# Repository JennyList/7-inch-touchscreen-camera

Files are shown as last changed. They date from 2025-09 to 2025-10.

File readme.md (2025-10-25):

# A camera enclosure for the 1st gen Rpi 7" touch screen, with interchangeable camera modules

Jenny List 2025
CC-BY-SA 4.0

## About

I need a camera mule, on which to test experimental digital camera designs. I had an RPi 4 and a 1st-gen Pi 7" touch screen, so I've made this camera enclosure. Think of it as a very chunky 7" tablet with a mounting on the rear for a modular 3D printed camera carrier. As shipped, it comes with a module for the RPi HQ camera.

For my needs it doesn't come with a battery, it will always be used in a static situation or as part of a rig  where USB-C power is available.
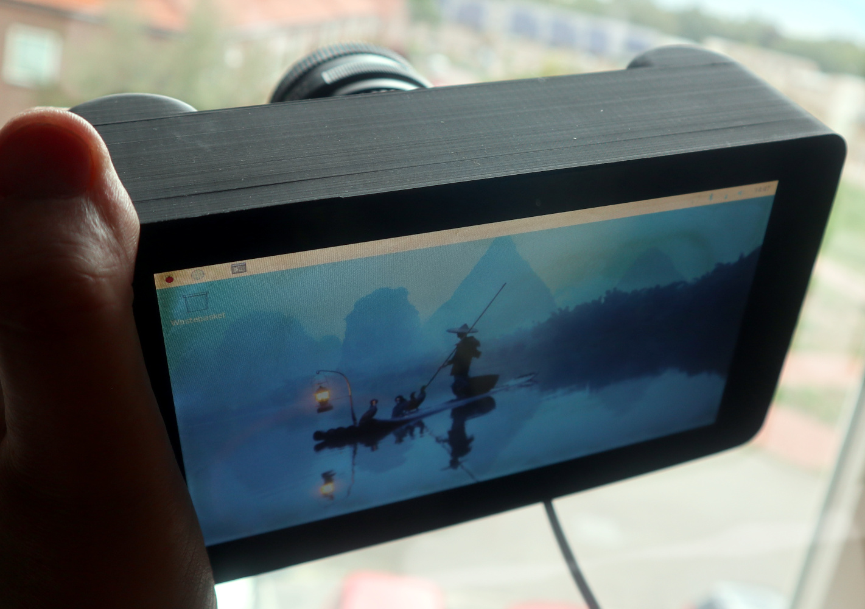
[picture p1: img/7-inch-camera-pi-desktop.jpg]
A picture of the camera.


## You Will Need:

Prints of the following modules from 7-inch-camera.scad. Use full supports and a brim.
1. cameraChassis()
2. cameraGripPanel()
3. HQCameraFrontPlate()

A print of the contents of camera-collar.scad. Use full supports and a brim.

A Pi 1/2/3/4 model B+

A 1st gen 7" Raspberry Pi touch screen and mounting kit.

4 M3 screws for the screen.

Assorted self-tapping screws for assembly.

## To Assemble:

The parts appear as follows:

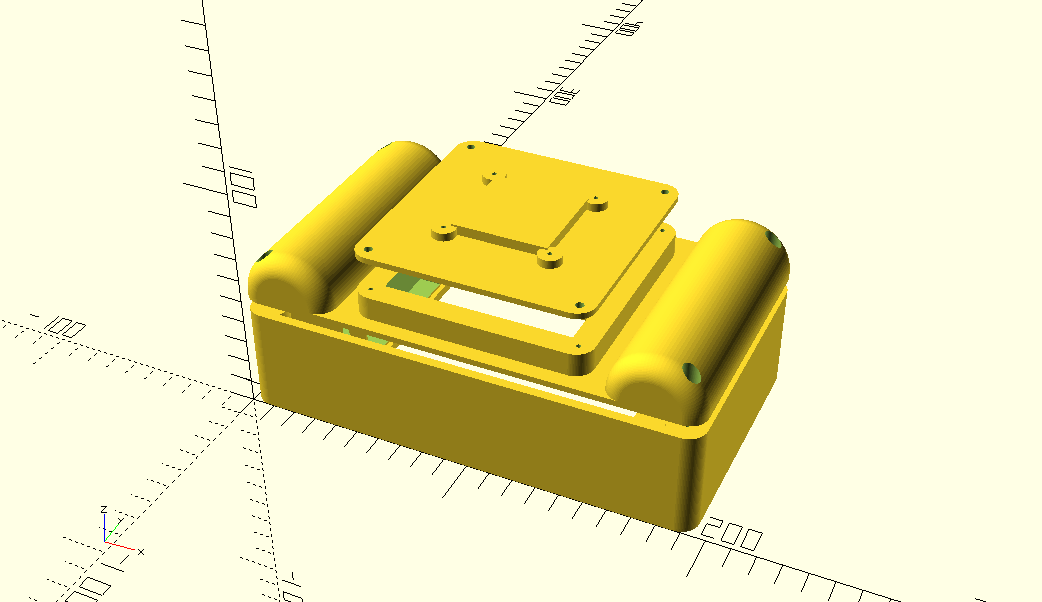
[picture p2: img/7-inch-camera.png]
The main parts of the camera.


The diagram above shows how the parts locate, though the HQ camera front plate is shown upside down as it is printed. 

It's suggested you mount the Pi to the display first using the included mounting kit and making sure it all works, before mounting the assembly to the chassis with four M3 screws. Then mount the grip panel to the back with four self-tapping screws. You should be able to see the Pi through a 100mm by 100mm opening in the front, this should be enough to attach the camera cable from your front place, and assemble the whole thing with more self-tapping screws.

The camera front plate as distributed is for the HQ camera. It attaches to the front with four self-tappers, with its rear electronics in the enclosure and the cable passing through the slot. The camera collar fits on top of the camera and is secured with four moew screws, supporting and protecting the module while allowing space for lens attachment.

## Software

Any RPi camera software shopuld be find with this, as long as it supports whatever camera module you are using. I'm trying this: (https://github.com/Gordon999/RPiCamGUI).

## Licence

This model is licensed under the [Creative Commons Attribution Share Alike 4.0 International licence](license.md).



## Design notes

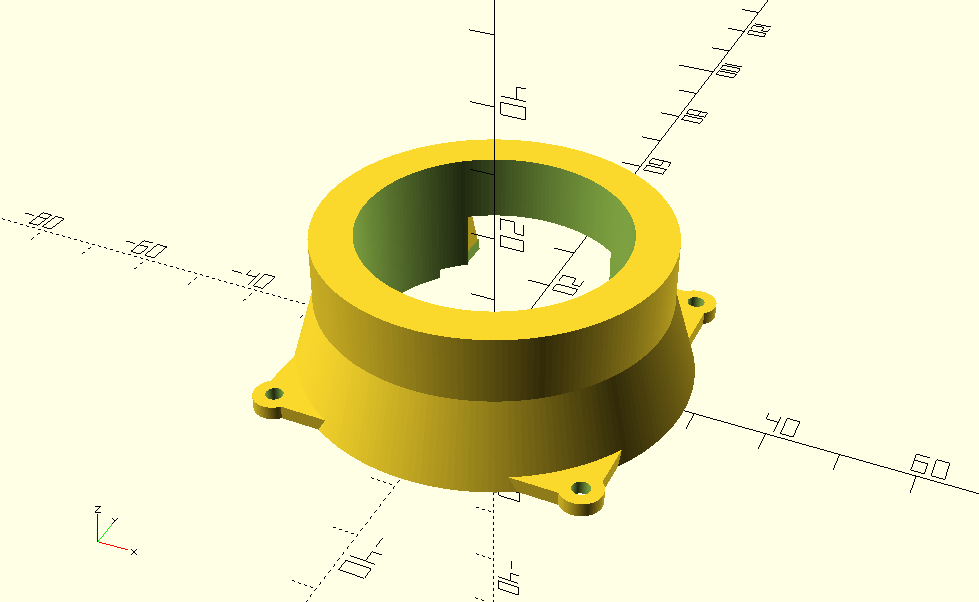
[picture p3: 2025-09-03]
img/camera-collar.png

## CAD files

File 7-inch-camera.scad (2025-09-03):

/*

An enclosure and HQ camera module mount for the first-generation 7" Pi touchscreen
Jenny List 2025
CC-BY-SA 4.0

*/

$fn=90;

include <./square-HQ-camera-mounting-plate.scad>


module ScreenOutline(width,height,cornerRadius){
     hull() {
         translate([cornerRadius,cornerRadius,0]) circle(cornerRadius);
         translate([width-cornerRadius,cornerRadius,0]) circle(cornerRadius);
         translate([width-cornerRadius,height-cornerRadius,0]) circle(cornerRadius);
         translate([cornerRadius,height-cornerRadius,0]) circle(cornerRadius);
     }
    
}

module grip(){
    rotate_extrude(angle=180){
        translate([-20,0,0]){
            difference() {
                ScreenOutline(40,113,8);
                square([20,113]);
            }
        }
    }
}

// Main box chassis
module cameraChassis(){
    difference(){
        union(){
            linear_extrude(45.5){ //main box structure
                difference(){
                    ScreenOutline(195,113,8); 
                    translate([4,4,0]) ScreenOutline(187,105,3);
                }
            }
            translate([28.18,0,9]) cube([15,113,4]); //Mounting strap for screen
            translate([154.38,0,9]) cube([15,113,4]); //Mounting strap for screen      
            translate([8,8,35.5]) cylinder(10,8,8); //lugs for back mounting
            translate([187,8,35.5]) cylinder(10,8,8);
            translate([187,105,35.5]) cylinder(10,8,8);
            translate([8,105,35.5]) cylinder(10,8,8);
            translate([0,20,18.5]) cube([45,65,24]); //pi ports
            translate([116,84,19.5]) cube([22,29,12]); //pi power
            translate([87.5,98,15.5]) cube([20,15,20]); //tripod block    
        }
        translate([1,1,0]) linear_extrude(1.5) ScreenOutline(193,111,7); //cut out for screen glass
        translate([35.68,22.91,0]) cylinder(20,1.75,1.75); //screw holes for screen
        translate([35.68,88.56,0]) cylinder(20,1.75,1.75);
        translate([161.88,22.91,0]) cylinder(20,1.75,1.75);
        translate([161.88,88.56,0]) cylinder(20,1.75,1.75);
        translate([8,8,0]) cylinder(50,1,1); //holes in back mounting lugs for screw threads
        translate([187,8,5.5]) cylinder(45,1,1);
        translate([187,105,5.5]) cylinder(45,1,1);
        translate([8,105,5.5]) cylinder(45,1,1);
        translate([35.68,22.91,13.5]) cylinder(230,3.25,3.25);//access for screen screw
        translate([0,21,19.5]) cube([100,63,22]); //pi ports
        translate([117,82,20.5]) cube([20,100,10]); //pi power
        translate([97.5,113,25.5]) rotate([90,0,0]) cylinder(13.7,3.1,3.1);//tripod insert
    }
}

// rear panel with grips and camera face
module cameraGripPanel(){
    difference(){
        union(){
            linear_extrude(4) ScreenOutline(195,113,8); //main rear panel
            translate([20,113,4]) rotate([90,0,0]){ grip(); } //hand grips
            translate([175,113,4]) rotate([90,0,0]){ grip(); }
            translate([47.5,6.5,4]) linear_extrude(10) ScreenOutline(100,100,8); // pedestal for camera assembly
        }
        linear_extrude(1.5){ 
            difference(){
                translate([-0.25,-0.25,0])ScreenOutline(195.5,113.5,8.75); //cut out to fit back of box structure
                translate([4.25,4.25,0]) ScreenOutline(186.5,104.5,7);
            }
        }
        translate([8.25,8.25,0]) cylinder(1.5,8.25,8.25); //lugs for back mounting
        translate([186.75,8.25,0]) cylinder(1.5,8.25,8.25); 
        translate([186.75,104.75,0]) cylinder(1.5,8.25,8.25); 
        translate([8.25,104.75,0]) cylinder(1.5,8.25,8.25);
        translate([8,8,0]) cylinder(45,1.75,1.75); //holes in back mounting lugs
        translate([187,8,0]) cylinder(45,1.75,1.75);
        translate([187,105,0]) cylinder(45,1.75,1.75);
        translate([8,105,0]) cylinder(45,1.75,1.75);
        translate([8,8,4]) cylinder(45,3.5,3.5); //holes for screw heads
        translate([187,8,4]) cylinder(45,3.5,3.5);
        translate([187,105,4]) cylinder(45,3.5,3.5);
        translate([8,105,4]) cylinder(45,3.5,3.5);
        translate([57.5,16.5,0]) cube([80,80,20]); //cutout behind camera assembly
        translate([53.5,12.5,0]) cylinder(45,1,1); //holes in camera pedestal for screw threads
        translate([141.5,12.5,0]) cylinder(45,1,1);
        translate([141.5,100.5,0]) cylinder(45,1,1);
        translate([53.5,100.5,0]) cylinder(45,1,1);
    }
}

module HQCameraFrontPlate(){ //Camera plate
    difference(){
        translate([47.5,6.5,0]) linear_extrude(2.5) ScreenOutline(100,100,8);
        translate([70,29,0]) cube([55,55,2.5]); //cutout for pi camera mount
        translate([53.5,12.5,0]) cylinder(45,1.75,1.75); //holes for screws
        translate([141.5,12.5,0]) cylinder(45,1.75,1.75);
        translate([141.5,100.5,0]) cylinder(45,1.75,1.75);
        translate([53.5,100.5,0]) cylinder(45,1.75,1.75);
    }
    translate([97.5,56.5,1.25]) SquarePiHQcameraMountingPlateWithCollarHoles();
}

//Draw the three parts
cameraChassis();
translate([0,0,50]) cameraGripPanel();
translate([0,0,80]) HQCameraFrontPlate();

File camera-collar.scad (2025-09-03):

/*

A protective collar for a Raspberry Pi HQ camera
Jenny List 2020
CC-BY-SA 4.0

*/


module collarSolid() {
    translate([0,0,12.0]) cylinder(9.5,25,25,$fa=1,$fn=200,false);//upper collar
    cylinder(12.0,28.5,25,$fa=1,$fn=200,false);//conical skirt
    translate([-24.5,-24.5,0]) cube([49,49,2],false);  //skirt for screw holes
    //four collar fixing screws
    translate([22.5,22.5,1]) cylinder(2,3,3,$fn=90,true);
    translate([22.5,-22.5,1]) cylinder(2,3,3,$fn=90,true);
    translate([-22.5,22.5,1]) cylinder(2,3,3,$fn=90,true);
    translate([-22.5,-22.5,1]) cylinder(2,3,3,$fn=90,true);
}

module collarCutaway(){
    cylinder(22.5,19,19,$fn=200,false);
    translate([-5.25,-23.3,0]) cube([10.5,5.1,12.0],false);//clamp protrusion
    difference(){ //tripod mount protrusion
        translate([0,3.9,2]) rotate([0,0,45]) cube([25,25,10.0
    ],false);   
        translate([-24,15,2]) cube([10,30,10.0],false); 
        translate([14,15,2]) cube([10,30,10.0],false);
    }
    translate([-14,19.5,0]) cube([28,12.5,2],false); //bottom of tripod mount
    translate([-19.5,-19.5,0]) cube([39,39,2],false);  //pcb
    //four camera fixing screws
    translate([15,15,2.75]) cylinder(1.5,3,3,true);
    translate([15,-15,2.75]) cylinder(1.5,3,3,true);
    translate([-15,15,2.75]) cylinder(1.5,3,3,true);
    translate([-15,-15,2.75]) cylinder(1.5,3,3,true);
    //four collar fixing screws
    translate([22.5,22.5,2.5]) cylinder(5,1.25,1.25,$fn=90,true);
    translate([22.5,-22.5,2.5]) cylinder(5,1.25,1.25,$fn=90,true);
    translate([-22.5,22.5,2.5]) cylinder(5,1.25,1.25,$fn=90,true);
    translate([-22.5,-22.5,2.5]) cylinder(5,1.25,1.25,$fn=90,true);
    //Fil in leftover protrusion between camera fixing screw and tripod mount
    translate([-14.25,11.5,2]) cube([28.5,5,1.5],false);
}

//Combine both outer and cutaway
difference(){
    collarSolid();
    collarCutaway();
}

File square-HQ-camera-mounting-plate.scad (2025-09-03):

/*

A flat square mounting plate for a Raspberry Pi HQ camera
Jenny List 2020
CC-BY-SA 4.0

*/
module SquarePiHQcameraMountingPlate(){
    //Recess for camera
    difference() {
        union(){ //camera plate and back box
            cube([55,55,2.5],true);
            translate([0,0,2.5]) cube([41,41,6],true);
        }
        translate([0,0,-0.5]) cube([36,36,10.5],true); //hollow it out  
        translate([0,16.75,0]) rotate([45,0,0]) cube([22,20,3.5],true); //somewhere for the cable
        translate([0,17.5,-1.25]) cube([25,2.5,10],true); // Extra space round connector
    }
    
    
    //screw pillars
    module cameraScrewPillar(angle=0){
        rotate(angle){
            difference() {
                union(){
                    cylinder(6,2.75,2.75,false);
                    translate([-3,-3,0]) linear_extrude(6) polygon(points=[[5,5],[5,0],[0,0],[0,5]]); 
                }
                cylinder(6,1,1,false);
            }
        } 
    }
    translate([-15,-15,-1.25]){
        cameraScrewPillar(0);
    }
    translate([15,-15,-1.25]){
        cameraScrewPillar(90);
    }
    translate([15,15,-1.25]){
        cameraScrewPillar(180);
    }
    translate([-15,15,-1.25]){
        cameraScrewPillar(270);
    }
}


//collar screw pillars
module collarScrewPillar(){
        union() {
            cylinder(6,5,5,false);
        }
}
//collar screw pillar holes
module collarScrewPillarHole(){
        union() {
            cylinder(6,1,1,false);
        }
}

module SquarePiHQcameraMountingPlateWithCollarHoles(tripodMarker=false){
    difference(){
        union(){
            SquarePiHQcameraMountingPlate();
            //four collar fixing pillars
            translate([0,0,-1.25]){
                translate([22.5,22.5,0]) collarScrewPillar();
                translate([22.5,-22.5,0]) collarScrewPillar();
                translate([-22.5,22.5,0]) collarScrewPillar();
                translate([-22.5,-22.5,0]) collarScrewPillar();
            }
        }
        
        //four collar fixing screws
        translate([0,0,-1.25]){
            translate([22.5,22.5,0]) collarScrewPillarHole();
            translate([22.5,-22.5,0]) collarScrewPillarHole();
            translate([-22.5,22.5,0]) collarScrewPillarHole();
            translate([-22.5,-22.5,0]) collarScrewPillarHole();
        }
    }
    //Show position of tripod mount ar 31mm y direction
    if(tripodMarker == true){
        translate([-9.5,31,-5.5]) cube([19,5,11]);
    }
}

//SquarePiHQcameraMountingPlateWithCollarHoles(tripodMarker=true);
